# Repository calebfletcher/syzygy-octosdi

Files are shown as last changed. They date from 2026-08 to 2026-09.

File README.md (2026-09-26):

# syzygy-octosdi

SYZYGY™ TXR4 Compatible 3G-SDI Pod, with quad inputs and quad outputs.

Compatible with the SYZYGY Specification Version 1.1.1. The "SYZYGY™" mark is owned by Opal Kelly.

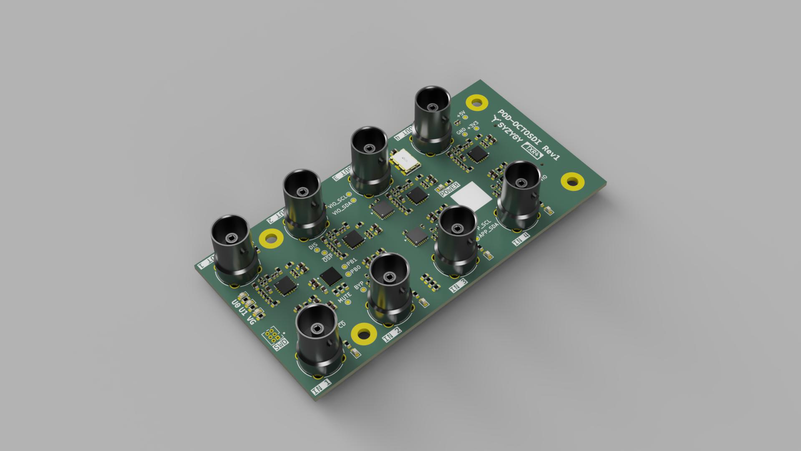
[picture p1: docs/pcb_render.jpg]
PCB Render


## Features
- SYZYGY TXR4 Pod
- 4x 3D-SDI inputs and 4x 3G-SDI outputs, all independent
- Full-size BNC connectors
- TI LMH0344 Cable Equalizers
- Semtech GS2988 Cable Drivers
- Lock/Signal Present LEDs at each BNC
- 148.5MHz oscillator on REFCLK
- I2C I/O expanders for all driver/equalizer control and status signals
- SmartVIO STM32G031 microcontroller with ability to measure VIO voltage

## Limitations
- Only 3G-SDI is supported
- There is no 148.5/1.001 MHz oscillator support
  - The board has only been designed for fractional framerates to keep the design a bit simpler. Depending on your FPGA, there may be enough tolerance on the MGT PLL to allow fractional rate inputs to be received despite it not being the correct frequency. This is the case at least for Xilinx Ultrascale+ GTYs with a +/-1250 ppm tolerance. However, this will not work for the transmitters which require the exact frequency.
- No reclockers on the board. It is designed to be plugged directly into an FPGA so this likely has no impact on its use.

## BOM Substitutions
While this board has been designed to use LMH0344 for the cable EQs and GS2988 for the cable drivers, there is broad compatibility across Semtech and TIs SDI portfolio. As such, some unpopulated footprints are available for passives needed for one chip or another, in particular for replacing the GS2988 with a LMH0302. See TI's SNLA280 for a full list of available substitutes for cable drivers, and SNLA283 for cable equalizers.

## [Interactive BOM](https://html-preview.github.io/?url=https://github.com/calebfletcher/syzygy-octosdi/blob/main/docs/ibom.html)

## Ordering Details
Designed to meet JLCPCBs standard capabilities.

Four layers, 1.6 mm, 1 oz outer/0.5 oz inner, JLC04161H-7628 stackup, controlled impedance.

## SYZYGY Compatibility Table

Following the pod compatibility table in [Appendix A of the SYZYGY Specification Version 1.1.1](https://syzygyfpga.io/wp-content/uploads/2023/09/Syzygy-Specification-V1p1p1.pdf):

| Parameter | syzygy-octosdi |
|---|---|
| Type | SYZYGY Transceiver (TXR-4) |
| Maximum 5V supply current | 0 mA |
| Maximum 3.3V supply current | 1.2 A (provisional design budget) |
| VIO supply voltage(s) | 1.8 V, 2.5 V, or 3.3 V |
| Maximum VIO supply current | 10 mA (provisional design budget) |
| Total number of I/O | 4 single-ended (S0–S3) |
| Number of differential I/O pairs (Standard pod only) | N/A (TXR-4 pod) |
| Transceiver lanes | 4 RX and 4 TX, plus REFCLK input |
| Width | Single |

The current budgets are conservative estimates from the schematic and component specifications; they have not been verified by measurement. The 5V pin is routed only to a test point. VIO powers the I/O side of the two expanders and the control-signal pull-ups.

## SYZYGY Pinout
Pinout for CN1 (QTH-020-01-F-D-DP-A):

| Pin number | Pin name | Pin net |
|---|---|---|
| 01 | SCL\_01 | VIO\_I2C.SCL |
| 02 | +5V\_02 | +5V |
| 03 | SDA\_03 | VIO\_I2C.SDA |
| 04 | R\_GA\_04 | R\_GA |
| 05 | RX0P\_05 | RX0.P |
| 06 | TX0P\_06 | TX0.P |
| 07 | RX0N\_07 | RX0.N |
| 08 | TX0N\_08 | TX0.N |
| 09 | RX1P\_09 | RX1.P |
| 10 | TX1P\_10 | TX1.P |
| 11 | RX1N\_11 | RX1.N |
| 12 | TX1N\_12 | TX1.N |
| 13 | REFCLKP\_13 | REFCLK.P |
| 14 | S0\_14 | I2C.SCL |
| 15 | REFCLKN\_15 | REFCLK.N |
| 16 | S1\_16 | I2C.SDA |
| 17 | S2\_17 | ~{RESET} |
| 18 | S3\_18 | ~{INT} |
| 19 | S4\_19 | NC |
| 20 | S5\_20 | NC |
| 21 | S6\_21 | NC |
| 22 | S7\_22 | NC |
| 23 | S8\_23 | NC |
| 24 | S9\_24 | NC |
| 25 | RX3P\_25 | RX3.P |
| 26 | TX3P\_26 | TX3.P |
| 27 | RX3N\_27 | RX3.N |
| 28 | TX3N\_28 | TX3.N |
| 29 | RX2P\_29 | RX2.P |
| 30 | TX2P\_30 | TX2.P |
| 31 | RX2N\_31 | RX2.N |
| 32 | TX2N\_32 | TX2.N |
| 33 | P2C\_CLKP\_33 | NC |
| 34 | C2P\_CLKP\_34 | NC |
| 35 | P2C\_CLKN\_35 | NC |
| 36 | C2P\_CLKN\_36 | NC |
| 37 | RSVD\_37 | NC |
| 38 | RSVD\_38 | NC |
| 39 | VIO1\_39 | VIO |
| 40 | +3.3V\_40 | +3V3 |
| G1 | GND\_G1 | GND |
| G2 | GND\_G2 | GND |
| G3 | GND\_G3 | GND |
| G4 | GND\_G4 | GND |

## SmartVIO STM32 Pinout
Pinout for U11 (STM32G031G8Ux):

| Pin number | Pin name | Pin net |
|---|---|---|
| 1 | PC14\_1 | NC |
| 2 | PC15\_2 | NC |
| 3 | VDD\_3 | +3V3 |
| 4 | VSS\_4 | GND |
| 5 | PF2\_5 | SmartVIO/NRST |
| 6 | ADC1\_IN0\_6 | R\_GA |
| 7 | ADC1\_IN1\_7 | VIO |
| 8 | PA2\_8 | VIO\_GOOD |
| 9 | PA3\_9 | ~{VIO\_GOOD} |
| 10 | PA4\_10 | NC |
| 11 | PA5\_11 | NC |
| 12 | PA6\_12 | NC |
| 13 | PA7\_13 | NC |
| 14 | PB0\_14 | Net-(U11-PB0) |
| 15 | PB1\_15 | Net-(U11-PB1) |
| 16 | PA8\_16 | NC |
| 17 | PC6\_17 | NC |
| 18 | PA9/PA11\_18 | NC |
| 19 | PA10/PA12\_19  | NC |
| 20 | SYS\_SWDIO\_20 | SmartVIO/SWDIO |
| 21 | SYS\_SWCLK\_21 | SmartVIO/SWCLK |
| 22 | PA15\_22 | NC |
| 23 | PB3\_23 | NC |
| 24 | PB4\_24 | SmartVIO/USER\_LED\_0 |
| 25 | PB5\_25 | SmartVIO/USER\_LED\_1 |
| 26 | I2C1\_SCL\_26  | VIO\_I2C.SCL |
| 27 | I2C1\_SDA\_27  | VIO\_I2C.SDA |
| 28 | PB8\_28 | NC |

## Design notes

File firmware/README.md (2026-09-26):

# SmartVIO LED and VIO ADC firmware

RTIC 2 keeps VIO_GOOD asserted, samples USER_LED_0's source at 10 Hz, and blinks USER_LED_1. Embassy STM32 owns the GPIO, ADC, and clock setup; TIM2 provides RTIC's monotonic clock. defmt logs are sent over RTT through the ST-Link.

| Signal or indicator | STM32 pin | Behaviour |
| --- | --- | --- |
| VIO_GOOD and its LED (D12) | PA2 | High continuously |
| VIO_GOOD_N | PA3 | Low continuously |
| USER_LED_0 (D11) | PB4 | Mirrors U6 P0.0 (SDI Out 1 SD_HD_N), sampled at 10 Hz |
| USER_LED_1 (D10) | PB5 | Blinks on for 1 s, off for 1 s |

VIO_GOOD and VIO_GOOD_N are asserted regardless of the measured voltage. VIO_GOOD also enables other board circuitry. Other board LEDs are driven by power or signal circuits, not directly by the STM32.

VIO is wired directly to PA1 / ADC1_IN1. The firmware samples VIO and the internal voltage reference every 100 ms and logs VIO in millivolts. It uses the factory VREF calibration to account for the actual ADC supply voltage.

At startup, I2C1 on PB6/PB7 accesses the two PCAL6416A expanders through the external VIO_I2C-to-APP_I2C bridge. U5 is at 7-bit address 0x20 and carries SDI input BYPASS, MUTE, and CD_N signals; U6 is at 0x21 and carries SDI output SD_HD_N, DISABLE_N, EQ_EN_N, and OSP_N signals. The firmware writes both configuration registers to 0xFF (all pins input), verifies them, and logs both raw port bytes and each named signal's electrical level once at startup (true = high, false = low; _N names remain active-low). Unconnected pins are omitted from the named logs. I2C errors are logged per device. After startup, U6 P0.0 is read every 100 ms to update USER_LED_0 (high = on); an I2C read error turns that LED off. The ADC is sampled on the same cycle.

From this directory:

    cargo build --release
    cargo run --release

cargo run flashes the STM32G031G8Ux using probe-rs and displays RTT logs. The target is thumbv6m-none-eabi and the probe uses SWD.

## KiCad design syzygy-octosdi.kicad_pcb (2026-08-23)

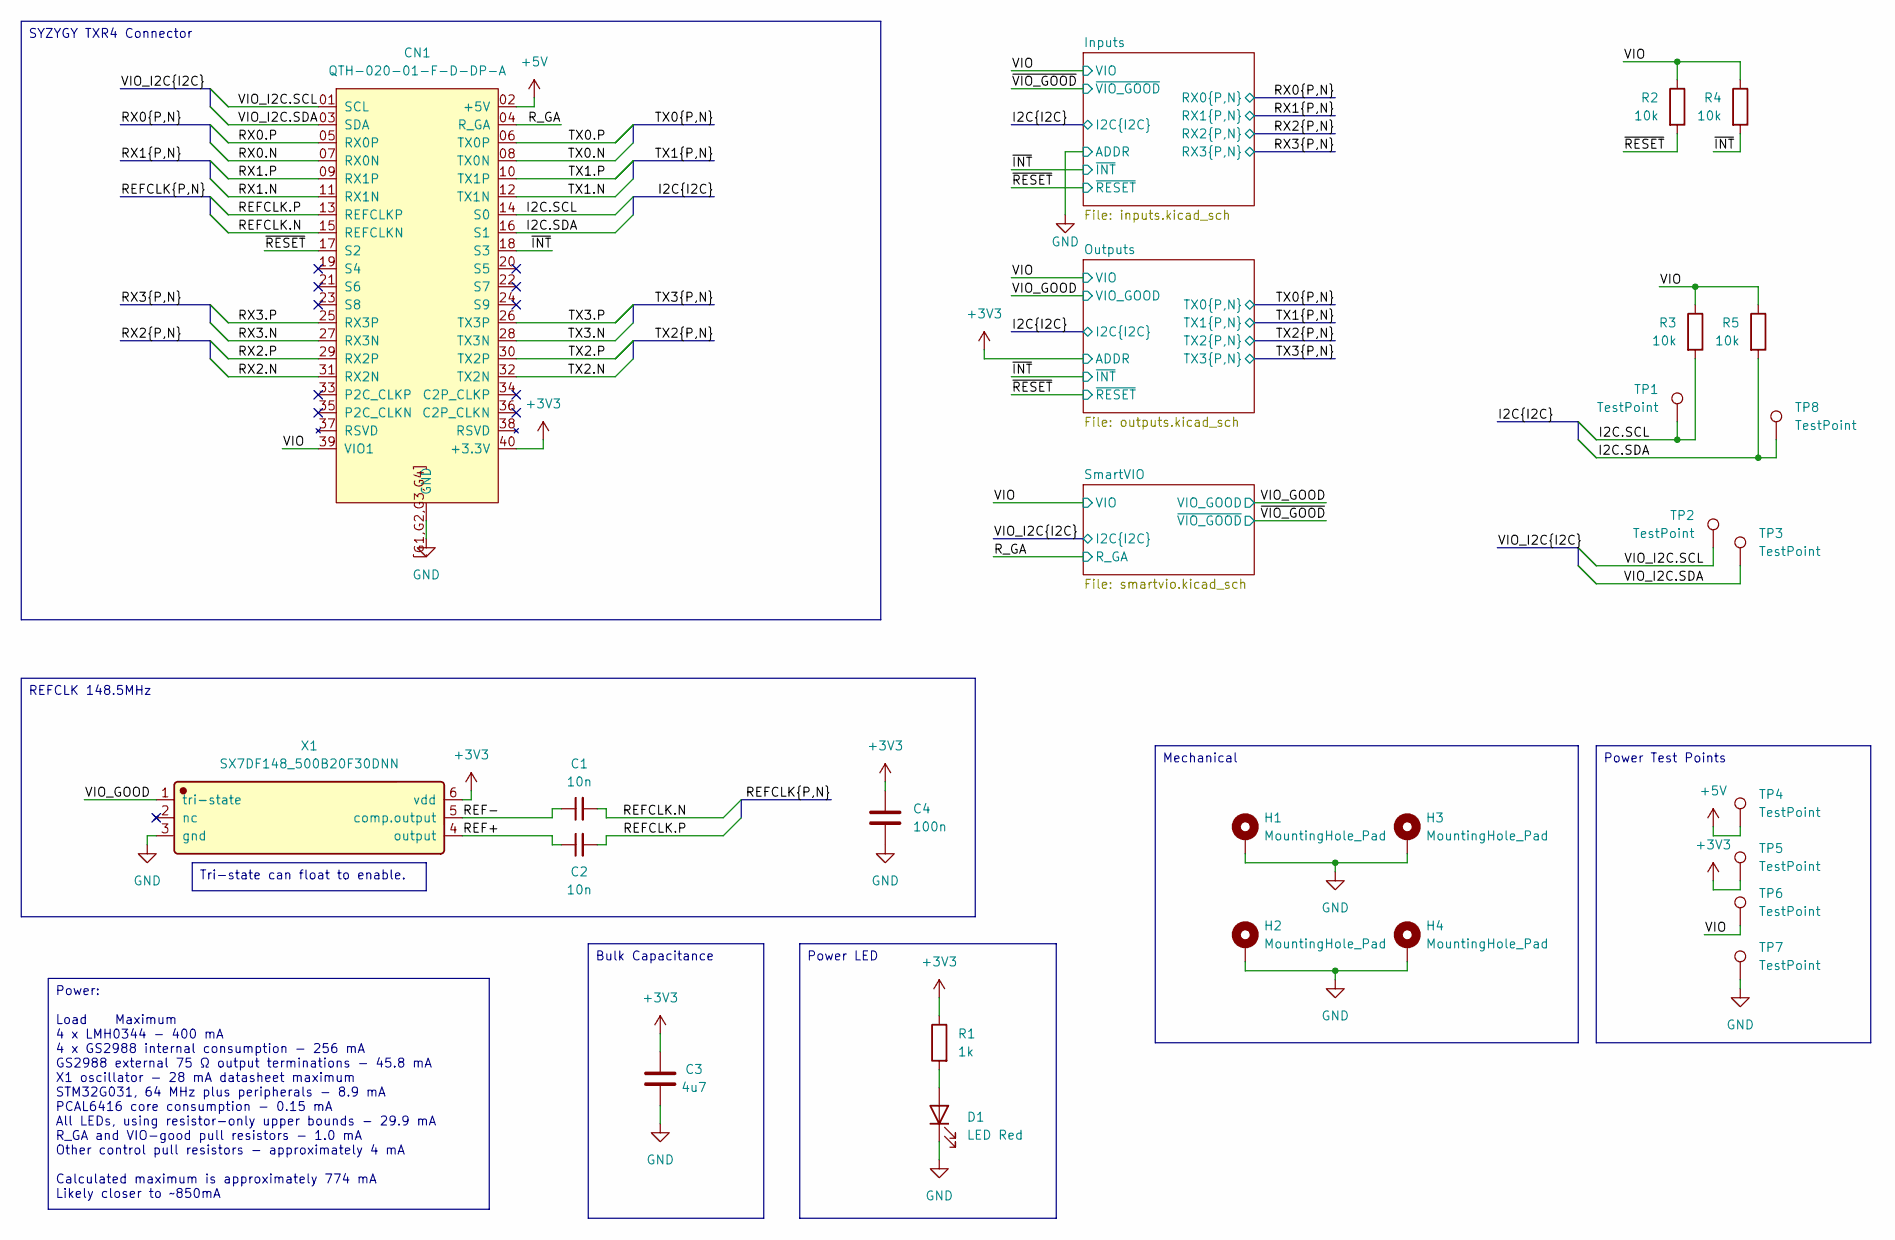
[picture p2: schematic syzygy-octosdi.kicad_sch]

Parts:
C1, C2: 10n; C_0402_1005Metric; LCSC C15195
C3: 4u7; C_0603_1608Metric; LCSC C69335
C4: 100n; C_0603_1608Metric; LCSC C282519
CN1: QTH-020-01-F-D-DP-A; Manufacturer Part QTH-020-01-F-D-DP-A; LCSC C5852101
D1: LED Red; LED_0603_1608Metric; LCSC C965799
H1, H2, H3, H4: MountingHole_Pad; MountingHole_3.2mm_M3_Pad
R1: 1k; R_0603_1608Metric; LCSC C21190
R2, R3, R4, R5: 10k; R_0603_1608Metric; LCSC C25804
TP1, TP2, TP3, TP4, TP5, TP6, TP7, TP8: TestPoint; TestPoint_Pad_D1.0mm
X1: SX7DF148_500B20F30DNN; Manufacturer Part SX7DF148.500B20F30DNN; LCSC C5179986

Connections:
+3V3: C3.1, C4.1, CN1.40 (+3.3V), R1.1, TP5.1 (1_1), X1.6 (vdd); also elsewhere on the board
+5V: CN1.02 (+5V), TP4.1 (1_1)
/I2C.SCL: CN1.14 (S0), R3.2, TP1.1 (1_1); also elsewhere on the board
/I2C.SDA: CN1.16 (S1), R5.2, TP8.1 (1_1); also elsewhere on the board
/REF+: C2.1, X1.4 (output)
/REF-: C1.1, X1.5 (comp.output)
/REFCLK.N: C1.2, CN1.15 (REFCLKN)
/REFCLK.P: C2.2, CN1.13 (REFCLKP)
/RX0.N: CN1.07 (RX0N); also elsewhere on the board
/RX0.P: CN1.05 (RX0P); also elsewhere on the board
/RX1.N: CN1.11 (RX1N); also elsewhere on the board
/RX1.P: CN1.09 (RX1P); also elsewhere on the board
/RX2.N: CN1.31 (RX2N); also elsewhere on the board
/RX2.P: CN1.29 (RX2P); also elsewhere on the board
/RX3.N: CN1.27 (RX3N); also elsewhere on the board
/RX3.P: CN1.25 (RX3P); also elsewhere on the board
/R_GA: CN1.04 (R_GA); also elsewhere on the board
/TX0.N: CN1.08 (TX0N); also elsewhere on the board
/TX0.P: CN1.06 (TX0P); also elsewhere on the board
/TX1.N: CN1.12 (TX1N); also elsewhere on the board
/TX1.P: CN1.10 (TX1P); also elsewhere on the board
/TX2.N: CN1.32 (TX2N); also elsewhere on the board
/TX2.P: CN1.30 (TX2P); also elsewhere on the board
/TX3.N: CN1.28 (TX3N); also elsewhere on the board
/TX3.P: CN1.26 (TX3P); also elsewhere on the board
/VIO: CN1.39 (VIO1), R2.1, R3.1, R4.1, R5.1, TP6.1 (1_1); also elsewhere on the board
/VIO_GOOD: X1.1 (tri-state); also elsewhere on the board
/VIO_I2C.SCL: CN1.01 (SCL), TP2.1 (1_1); also elsewhere on the board
/VIO_I2C.SDA: CN1.03 (SDA), TP3.1 (1_1); also elsewhere on the board
/~INT: CN1.18 (S3), R4.2; also elsewhere on the board
/~RESET: CN1.17 (S2), R2.2; also elsewhere on the board
GND: C3.2, C4.2, CN1.G1 (GND), CN1.G2 (GND), CN1.G3 (GND), CN1.G4 (GND), CN1.[G1,G2,G3,G4] (GND), D1.1 (K), H1.1 (1_1), H2.1 (1_1), H3.1 (1_1), H4.1 (1_1), TP7.1 (1_1), X1.3 (gnd); also elsewhere on the board
unnamed: D1.2 (A), R1.2

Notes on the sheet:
Power: Load Maximum 4 x LMH0344 - 400 mA 4 x GS2988 internal consumption - 256 mA GS2988 external 75 Ω output terminations - 45.8 mA X1 oscillator - 28 mA datasheet maximum STM32G031, 64 MHz plus peripherals - 8.9 mA PCAL6416 core consumption - 0.15 mA All LEDs, using resistor-only upper bounds - 2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
Mechanical
SYZYGY TXR4 Connector
Power Test Points
REFCLK 148.5MHz
Bulk Capacitance
Tri-state can float to enable.
Power LED

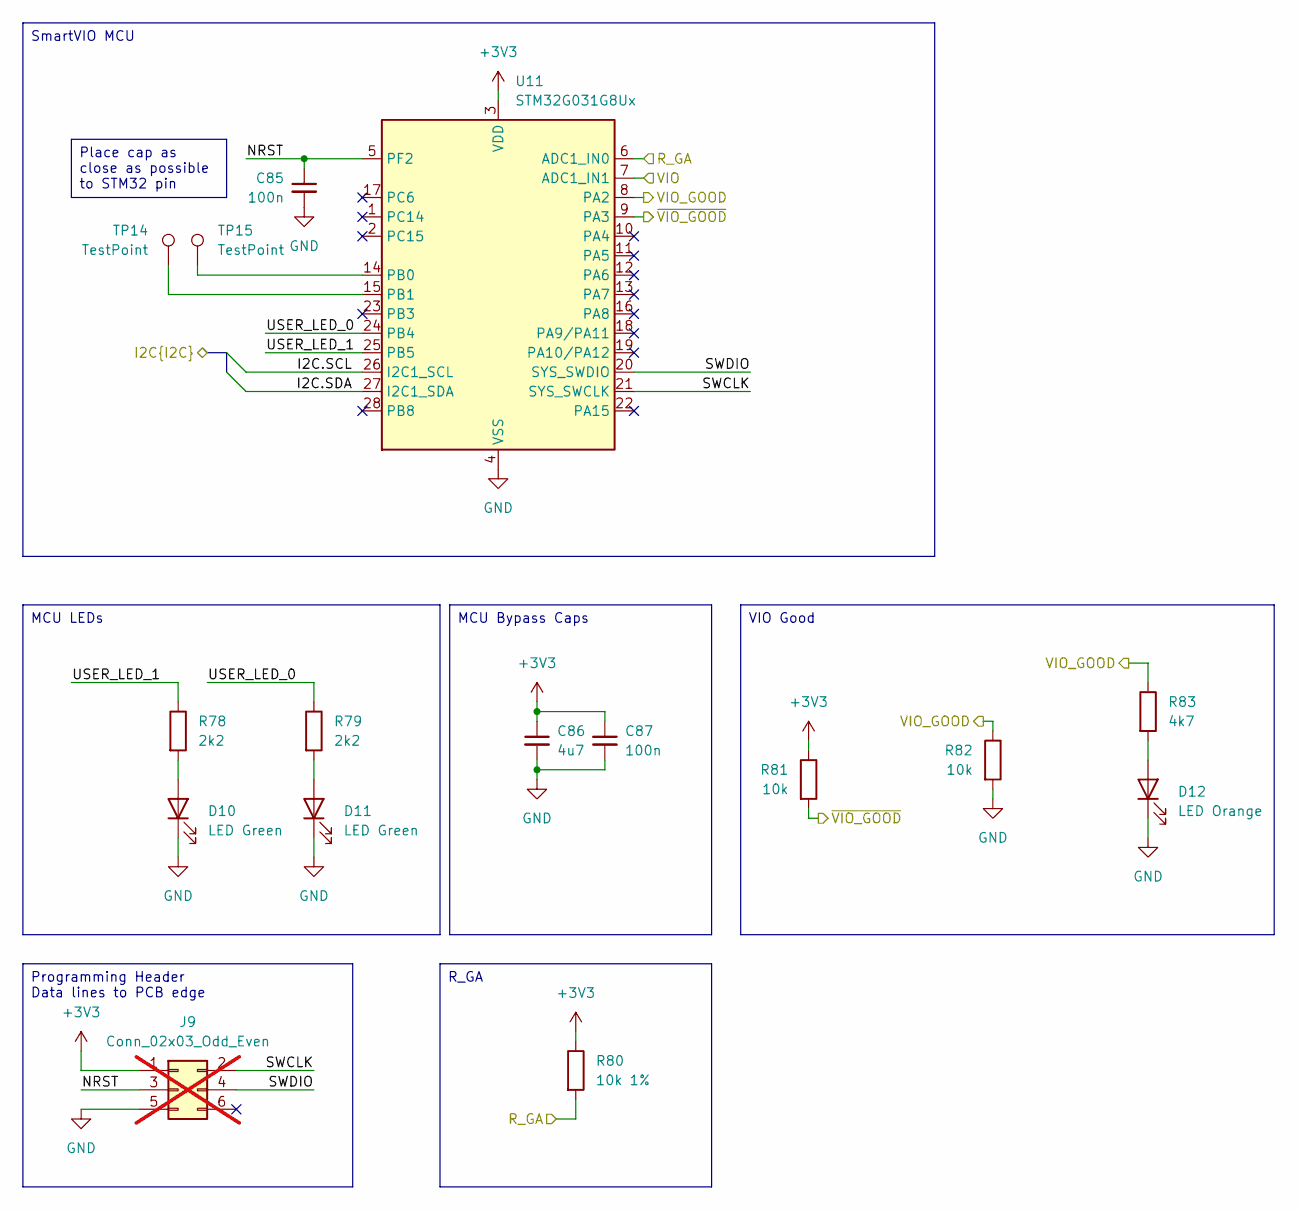
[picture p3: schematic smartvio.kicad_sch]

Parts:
C85, C87: 100n; C_0603_1608Metric; LCSC C282519
C86: 4u7; C_0603_1608Metric; LCSC C69335
D10, D11: LED Green; LED_0603_1608Metric; LCSC C965804
D12: LED Orange; LED_0603_1608Metric; LCSC C965800
J9: Conn_02x03_Odd_Even; PinHeader_2x03_P1.27mm_Vertical; not fitted
R78, R79: 2k2; R_0603_1608Metric; LCSC C2907005
R80: 10k 1%; R_0603_1608Metric; LCSC C25804
R81, R82: 10k; R_0603_1608Metric; LCSC C25804
R83: 4k7; R_0603_1608Metric; LCSC C2907034
TP14, TP15: TestPoint; TestPoint_Pad_D1.0mm
U11: STM32G031G8Ux; UFQFPN-28_STM; LCSC C432211

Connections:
+3V3: C86.1, C87.1, J9.1, R80.1, R81.1, U11.3 (VDD); also elsewhere on the board
/R_GA: R80.2, U11.6 (ADC1_IN0); also elsewhere on the board
/SmartVIO/NRST: C85.1, J9.3, U11.5 (PF2)
/SmartVIO/SWCLK: J9.2, U11.21 (SYS_SWCLK)
/SmartVIO/SWDIO: J9.4, U11.20 (SYS_SWDIO)
/SmartVIO/USER_LED_0: R79.1, U11.24 (PB4)
/SmartVIO/USER_LED_1: R78.1, U11.25 (PB5)
/VIO: U11.7 (ADC1_IN1); also elsewhere on the board
/VIO_GOOD: R82.1, R83.1, U11.8 (PA2); also elsewhere on the board
/VIO_I2C.SCL: U11.26 (I2C1_SCL); also elsewhere on the board
/VIO_I2C.SDA: U11.27 (I2C1_SDA); also elsewhere on the board
/~VIO_GOOD: R81.2, U11.9 (PA3); also elsewhere on the board
GND: C85.2, C86.2, C87.2, D10.1 (K), D11.1 (K), D12.1 (K), J9.5, R82.2, U11.4 (VSS); also elsewhere on the board
unnamed: D10.2 (A), R78.2
unnamed: D11.2 (A), R79.2
unnamed: D12.2 (A), R83.2
unnamed: TP15.1 (1_1), U11.14 (PB0)
unnamed: TP14.1 (1_1), U11.15 (PB1)

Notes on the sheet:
MCU Bypass Caps
VIO Good
MCU LEDs
Programming Header Data lines to PCB edge
Place cap as close as possible to STM32 pin
SmartVIO MCU
R_GA

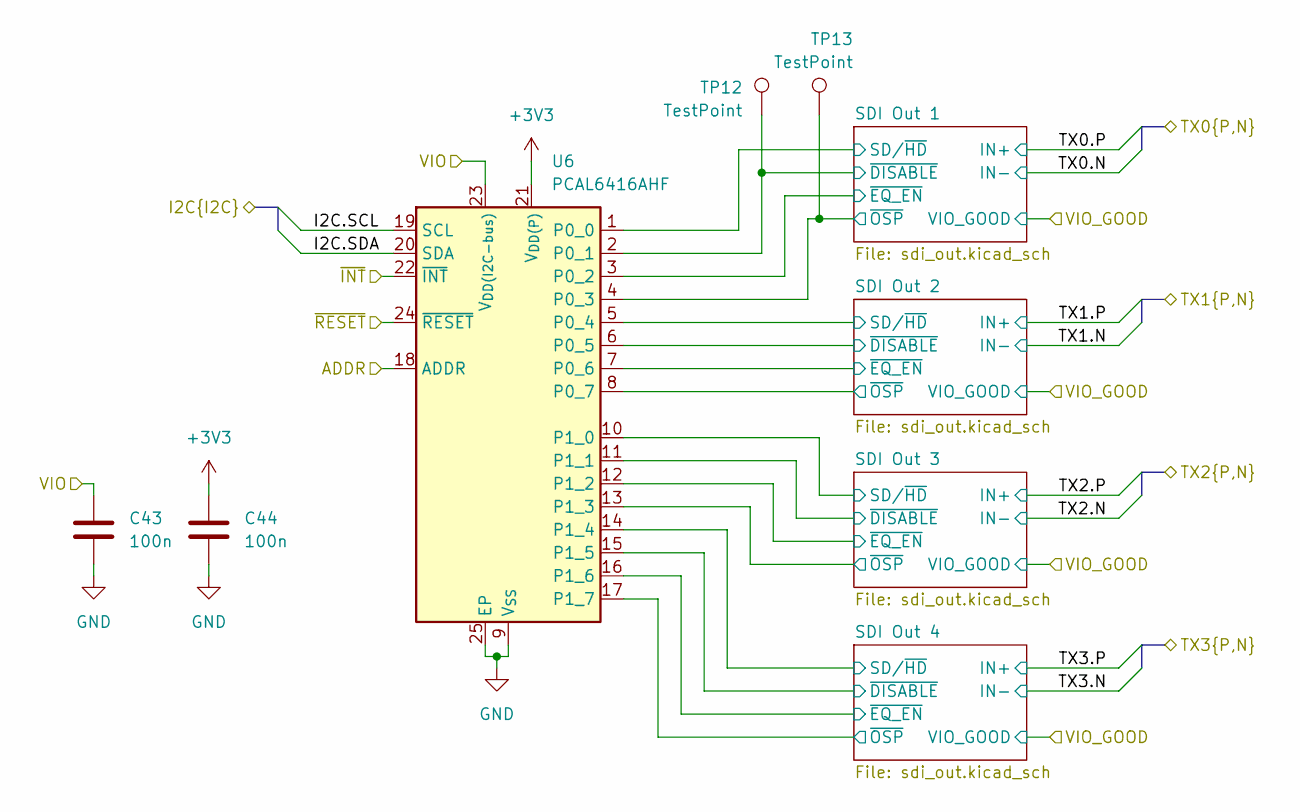
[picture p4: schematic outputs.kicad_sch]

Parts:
C43, C44: 100n; C_0402_1005Metric; LCSC C1525
TP12, TP13: TestPoint; TestPoint_Pad_D1.0mm
U6: PCAL6416AHF; HVQFN-24-1EP_4x4mm_P0.5mm_EP2.1x2.1mm; LCSC C2652287

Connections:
+3V3: C44.1, U6.18 (ADDR), U6.21 (V_{DD(P)}); also elsewhere on the board
/I2C.SCL: U6.19 (SCL); also elsewhere on the board
/I2C.SDA: U6.20 (SDA); also elsewhere on the board
/Outputs/SDI Out 1/SD/~HD: U6.1 (P0_0); also elsewhere on the board
/Outputs/SDI Out 1/~DISABLE: TP12.1 (1_1), U6.2 (P0_1); also elsewhere on the board
/Outputs/SDI Out 1/~EQ_EN: U6.3 (P0_2); also elsewhere on the board
/Outputs/SDI Out 1/~OSP: TP13.1 (1_1), U6.4 (P0_3); also elsewhere on the board
/Outputs/SDI Out 2/SD/~HD: U6.5 (P0_4); also elsewhere on the board
/Outputs/SDI Out 2/~DISABLE: U6.6 (P0_5); also elsewhere on the board
/Outputs/SDI Out 2/~EQ_EN: U6.7 (P0_6); also elsewhere on the board
/Outputs/SDI Out 2/~OSP: U6.8 (P0_7); also elsewhere on the board
/Outputs/SDI Out 3/SD/~HD: U6.10 (P1_0); also elsewhere on the board
/Outputs/SDI Out 3/~DISABLE: U6.11 (P1_1); also elsewhere on the board
/Outputs/SDI Out 3/~EQ_EN: U6.12 (P1_2); also elsewhere on the board
/Outputs/SDI Out 3/~OSP: U6.13 (P1_3); also elsewhere on the board
/Outputs/SDI Out 4/SD/~HD: U6.14 (P1_4); also elsewhere on the board
/Outputs/SDI Out 4/~DISABLE: U6.15 (P1_5); also elsewhere on the board
/Outputs/SDI Out 4/~EQ_EN: U6.16 (P1_6); also elsewhere on the board
/Outputs/SDI Out 4/~OSP: U6.17 (P1_7); also elsewhere on the board
/VIO: C43.1, U6.23 (V_{DD(I2C-bus)}); also elsewhere on the board
/~INT: U6.22 (~INT); also elsewhere on the board
/~RESET: U6.24 (~RESET); also elsewhere on the board
GND: C43.2, C44.2, U6.9 (V_{SS}), U6.25 (EP); also elsewhere on the board

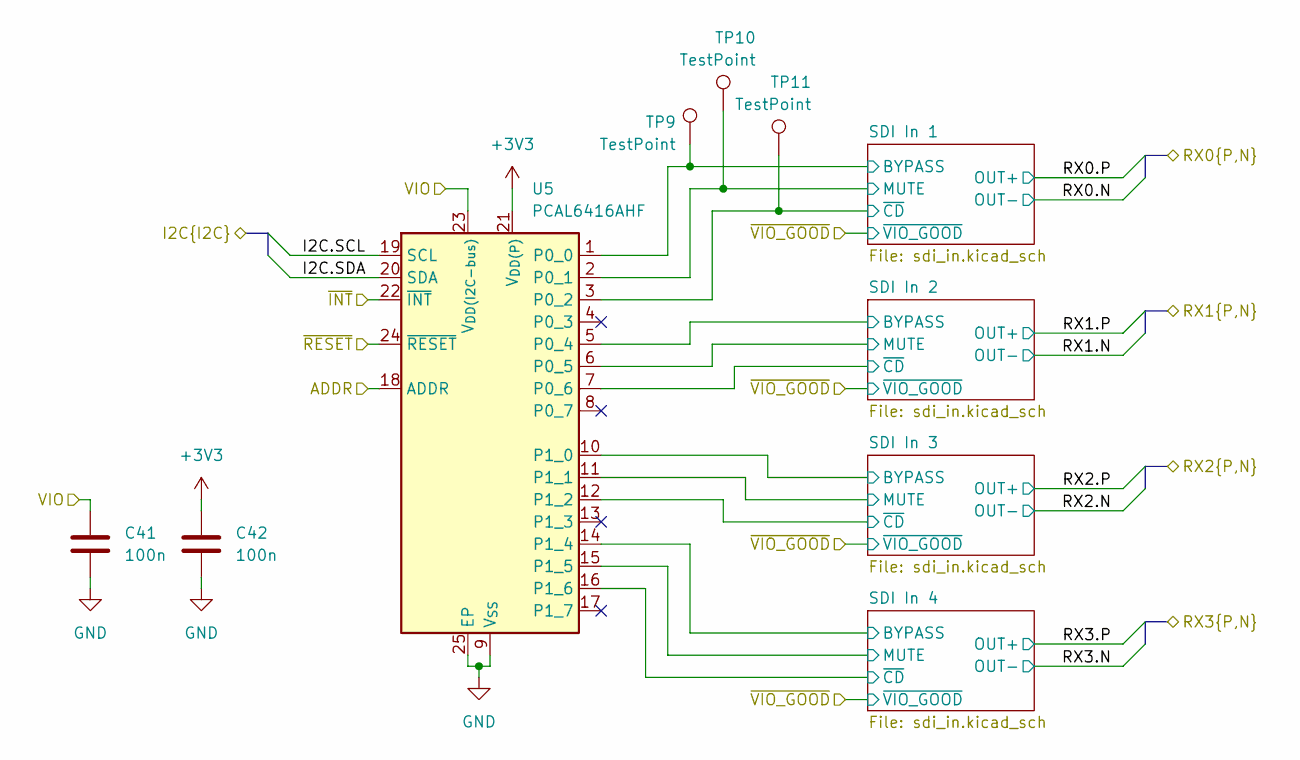
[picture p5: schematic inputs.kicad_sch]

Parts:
C41, C42: 100n; C_0402_1005Metric; LCSC C1525
TP9, TP10, TP11: TestPoint; TestPoint_Pad_D1.0mm
U5: PCAL6416AHF; HVQFN-24-1EP_4x4mm_P0.5mm_EP2.1x2.1mm; LCSC C2652287

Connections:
+3V3: C42.1, U5.21 (V_{DD(P)}); also elsewhere on the board
/I2C.SCL: U5.19 (SCL); also elsewhere on the board
/I2C.SDA: U5.20 (SDA); also elsewhere on the board
/Inputs/SDI In 1/BYPASS: TP9.1 (1_1), U5.1 (P0_0); also elsewhere on the board
/Inputs/SDI In 1/MUTE: TP10.1 (1_1), U5.2 (P0_1); also elsewhere on the board
/Inputs/SDI In 1/~CD: TP11.1 (1_1), U5.3 (P0_2); also elsewhere on the board
/Inputs/SDI In 2/BYPASS: U5.5 (P0_4); also elsewhere on the board
/Inputs/SDI In 2/MUTE: U5.6 (P0_5); also elsewhere on the board
/Inputs/SDI In 2/~CD: U5.7 (P0_6); also elsewhere on the board
/Inputs/SDI In 3/BYPASS: U5.10 (P1_0); also elsewhere on the board
/Inputs/SDI In 3/MUTE: U5.11 (P1_1); also elsewhere on the board
/Inputs/SDI In 3/~CD: U5.12 (P1_2); also elsewhere on the board
/Inputs/SDI In 4/BYPASS: U5.14 (P1_4); also elsewhere on the board
/Inputs/SDI In 4/MUTE: U5.15 (P1_5); also elsewhere on the board
/Inputs/SDI In 4/~CD: U5.16 (P1_6); also elsewhere on the board
/VIO: C41.1, U5.23 (V_{DD(I2C-bus)}); also elsewhere on the board
/~INT: U5.22 (~INT); also elsewhere on the board
/~RESET: U5.24 (~RESET); also elsewhere on the board
GND: C41.2, C42.2, U5.9 (V_{SS}), U5.18 (ADDR), U5.25 (EP); also elsewhere on the board

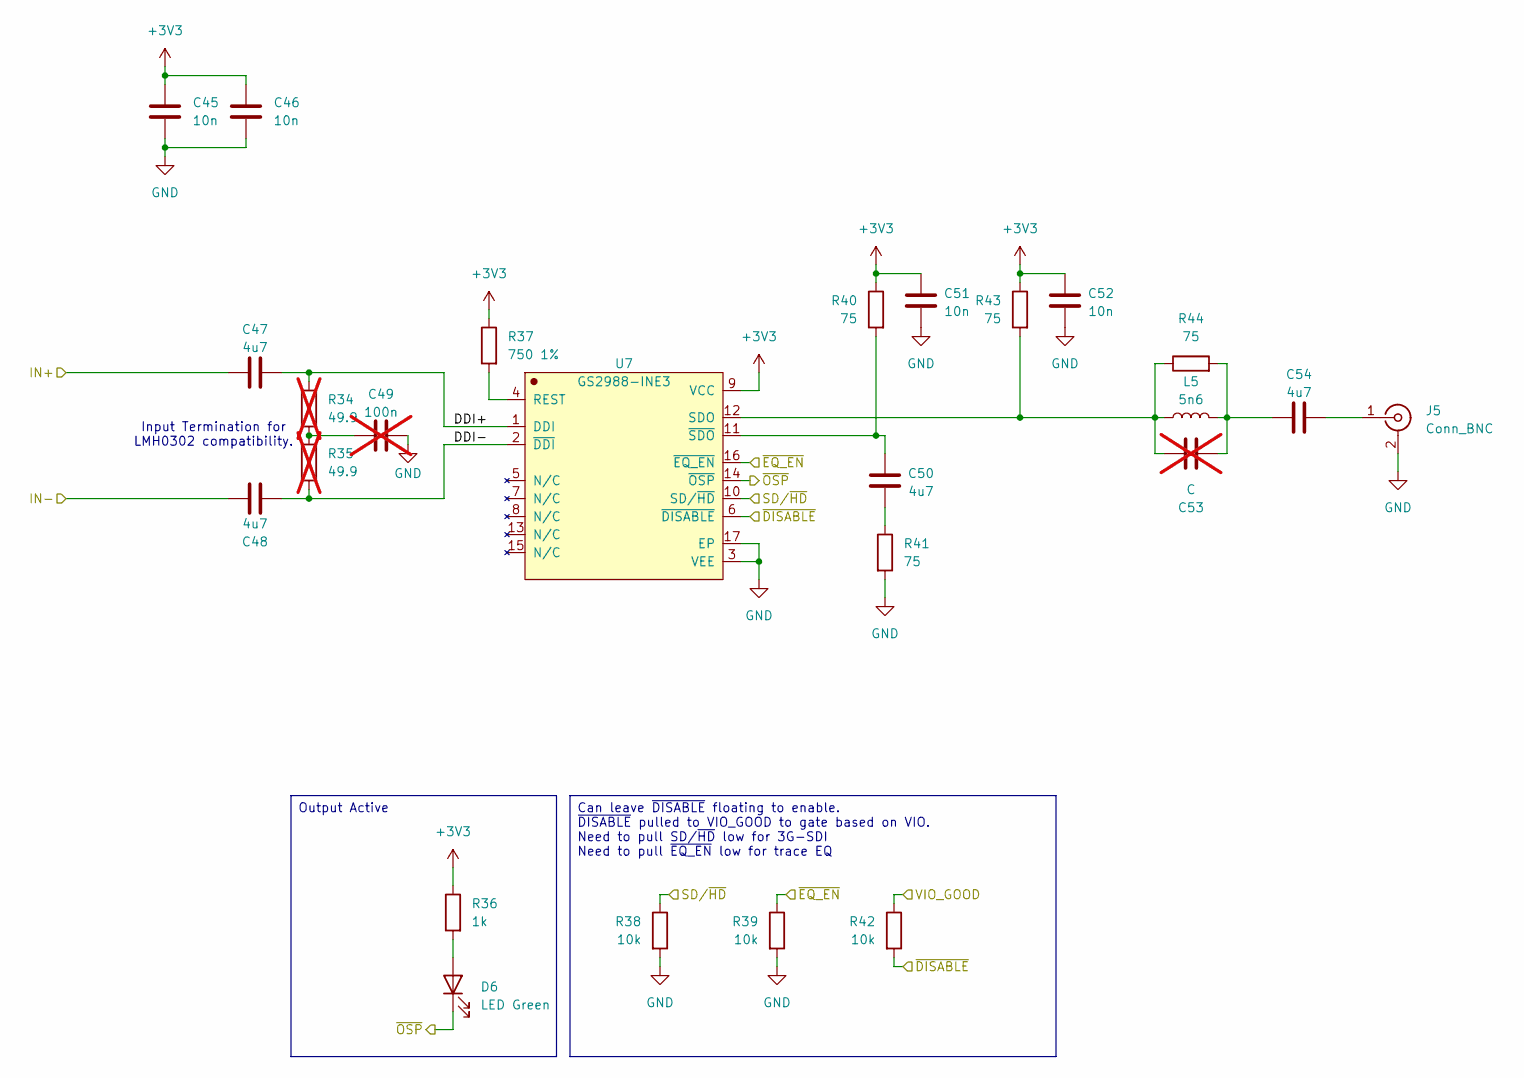
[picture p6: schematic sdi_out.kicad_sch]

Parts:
C45, C46, C51, C52: 10n; C_0402_1005Metric; LCSC C15195
C47, C48, C50, C54: 4u7; C_0603_1608Metric; LCSC C69335
C49: 100n; C_0402_1005Metric; LCSC C1525; not fitted
C53: C; C_0402_1005Metric; not fitted
D6: LED Green; LED_0603_1608Metric; LCSC C965804
J5: Conn_BNC; CONN_73171-1900_MOL; Manufacturer Part 731711900
L5: 5n6; L_0402_1005Metric; LCSC C3223990
R34, R35: 49.9; R_0402_1005Metric; not fitted
R36: 1k; R_0603_1608Metric; LCSC C21190
R37: 750 1%; R_0603_1608Metric; LCSC C118388
R38, R39, R42: 10k; R_0603_1608Metric; LCSC C25804
R40, R41, R43, R44: 75; R_0402_1005Metric; LCSC C324774
U7: GS2988-INE3; Manufacturer Part GS2988-INE3; LCSC C5367442

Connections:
+3V3: C45.1, C46.1, C51.1, C52.1, R36.1, R37.1, R40.1, R43.1, U7.9 (VCC); also elsewhere on the board
/Outputs/SDI Out 1/DDI+: C47.2, R34.1, U7.1 (DDI)
/Outputs/SDI Out 1/DDI-: C48.2, R35.2, U7.2 (~DDI)
/Outputs/SDI Out 1/SD/~HD: R38.1, U7.10 (SD/~HD); also elsewhere on the board
/Outputs/SDI Out 1/~DISABLE: R42.2, U7.6 (~DISABLE); also elsewhere on the board
/Outputs/SDI Out 1/~EQ_EN: R39.1, U7.16 (~EQ_EN); also elsewhere on the board
/Outputs/SDI Out 1/~OSP: D6.1 (K), U7.14 (~OSP); also elsewhere on the board
/TX0.N: C48.1; also elsewhere on the board
/TX0.P: C47.1; also elsewhere on the board
/VIO_GOOD: R42.1; also elsewhere on the board
GND: C45.2, C46.2, C49.2, C51.2, C52.2, J5.2 (Ext), R38.2, R39.2, R41.2, U7.3 (VEE), U7.17 (EP); also elsewhere on the board
unnamed: C49.1, R34.2, R35.1
unnamed: C50.2, R41.1
unnamed: C53.2, C54.1, L5.2, R44.2
unnamed: D6.2 (A), R36.2
unnamed: C54.2, J5.1 (In)
unnamed: R37.2, U7.4 (REST)
unnamed: C53.1, L5.1, R43.2, R44.1, U7.12 (SDO)
unnamed: C50.1, R40.2, U7.11 (~SDO)

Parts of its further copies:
C55, C56, C61, C62, C65, C66, C71, C72, C75, C76, C81, C82: 10n; C_0402_1005Metric; LCSC C15195
C57, C58, C60, C64, C67, C68, C70, C74, C77, C78, C80, C84: 4u7; C_0603_1608Metric; LCSC C69335
C59, C69, C79: 100n; C_0402_1005Metric; LCSC C1525; not fitted
C63, C73, C83: C; C_0402_1005Metric; not fitted
D7, D8, D9: LED Green; LED_0603_1608Metric; LCSC C965804
J6, J7, J8: Conn_BNC; CONN_73171-1900_MOL; Manufacturer Part 731711900
L6, L7, L8: 5n6; L_0402_1005Metric; LCSC C3223990
R45, R46, R56, R57, R67, R68: 49.9; R_0402_1005Metric; not fitted
R47, R58, R69: 1k; R_0603_1608Metric; LCSC C21190
R48, R59, R70: 750 1%; R_0603_1608Metric; LCSC C118388
R49, R50, R53, R60, R61, R64, R71, R72, R75: 10k; R_0603_1608Metric; LCSC C25804
R51, R52, R54, R55, R62, R63, R65, R66, R73, R74, R76, R77: 75; R_0402_1005Metric; LCSC C324774
U8, U9, U10: GS2988-INE3; Manufacturer Part GS2988-INE3; LCSC C5367442

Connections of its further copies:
+3V3: C55.1, C56.1, C61.1, C62.1, C65.1, C66.1, C71.1, C72.1, C75.1, C76.1, C81.1, C82.1, R47.1, R48.1, R51.1, R54.1, R58.1, R59.1, R62.1, R65.1, R69.1, R70.1, R73.1, R76.1, U8.9 (VCC), U9.9 (VCC), U10.9 (VCC); also elsewhere on the board
/Outputs/SDI Out 2/DDI+: C57.2, R45.1, U8.1 (DDI)
/Outputs/SDI Out 2/DDI-: C58.2, R46.2, U8.2 (~DDI)
/Outputs/SDI Out 2/SD/~HD: R49.1, U8.10 (SD/~HD); also elsewhere on the board
/Outputs/SDI Out 2/~DISABLE: R53.2, U8.6 (~DISABLE); also elsewhere on the board
/Outputs/SDI Out 2/~EQ_EN: R50.1, U8.16 (~EQ_EN); also elsewhere on the board
/Outputs/SDI Out 2/~OSP: D7.1 (K), U8.14 (~OSP); also elsewhere on the board
/Outputs/SDI Out 3/DDI+: C67.2, R56.1, U9.1 (DDI)
/Outputs/SDI Out 3/DDI-: C68.2, R57.2, U9.2 (~DDI)
/Outputs/SDI Out 3/SD/~HD: R60.1, U9.10 (SD/~HD); also elsewhere on the board
/Outputs/SDI Out 3/~DISABLE: R64.2, U9.6 (~DISABLE); also elsewhere on the board
/Outputs/SDI Out 3/~EQ_EN: R61.1, U9.16 (~EQ_EN); also elsewhere on the board
/Outputs/SDI Out 3/~OSP: D8.1 (K), U9.14 (~OSP); also elsewhere on the board
/Outputs/SDI Out 4/DDI+: C77.2, R67.1, U10.1 (DDI)
/Outputs/SDI Out 4/DDI-: C78.2, R68.2, U10.2 (~DDI)
/Outputs/SDI Out 4/SD/~HD: R71.1, U10.10 (SD/~HD); also elsewhere on the board
/Outputs/SDI Out 4/~DISABLE: R75.2, U10.6 (~DISABLE); also elsewhere on the board
/Outputs/SDI Out 4/~EQ_EN: R72.1, U10.16 (~EQ_EN); also elsewhere on the board
/Outputs/SDI Out 4/~OSP: D9.1 (K), U10.14 (~OSP); also elsewhere on the board
/TX1.N: C58.1; also elsewhere on the board
/TX1.P: C57.1; also elsewhere on the board
/TX2.N: C68.1; also elsewhere on the board
/TX2.P: C67.1; also elsewhere on the board
/TX3.N: C78.1; also elsewhere on the board
/TX3.P: C77.1; also elsewhere on the board
/VIO_GOOD: R53.1, R64.1, R75.1; also elsewhere on the board
GND: C55.2, C56.2, C59.2, C61.2, C62.2, C65.2, C66.2, C69.2, C71.2, C72.2, C75.2, C76.2, C79.2, C81.2, C82.2, J6.2 (Ext), J7.2 (Ext), J8.2 (Ext), R49.2, R50.2, R52.2, R60.2, R61.2, R63.2, R71.2, R72.2, R74.2, U8.3 (VEE), U8.17 (EP), U9.3 (VEE), U9.17 (EP), U10.3 (VEE), U10.17 (EP); also elsewhere on the board
unnamed: C59.1, R45.2, R46.1
unnamed: C60.2, R52.1
unnamed: C63.2, C64.1, L6.2, R55.2
unnamed: C69.1, R56.2, R57.1
unnamed: C70.2, R63.1
unnamed: C73.2, C74.1, L7.2, R66.2
unnamed: C79.1, R67.2, R68.1
unnamed: C80.2, R74.1
unnamed: C83.2, C84.1, L8.2, R77.2
unnamed: D7.2 (A), R47.2
unnamed: D8.2 (A), R58.2
unnamed: D9.2 (A), R69.2
unnamed: C64.2, J6.1 (In)
unnamed: C74.2, J7.1 (In)
unnamed: C84.2, J8.1 (In)
unnamed: R48.2, U8.4 (REST)
unnamed: C63.1, L6.1, R54.2, R55.1, U8.12 (SDO)
unnamed: C60.1, R51.2, U8.11 (~SDO)
unnamed: R59.2, U9.4 (REST)
unnamed: C73.1, L7.1, R65.2, R66.1, U9.12 (SDO)
unnamed: C70.1, R62.2, U9.11 (~SDO)
unnamed: R70.2, U10.4 (REST)
unnamed: C83.1, L8.1, R76.2, R77.1, U10.12 (SDO)
unnamed: C80.1, R73.2, U10.11 (~SDO)

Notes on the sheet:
Input Termination for LMH0302 compatibility.
Output Active
Can leave ~{DISABLE} floating to enable. ~{DISABLE} pulled to VIO_GOOD to gate based on VIO. Need to pull SD/~{HD} low for 3G-SDI Need to pull ~{EQ_EN} low for trace EQ

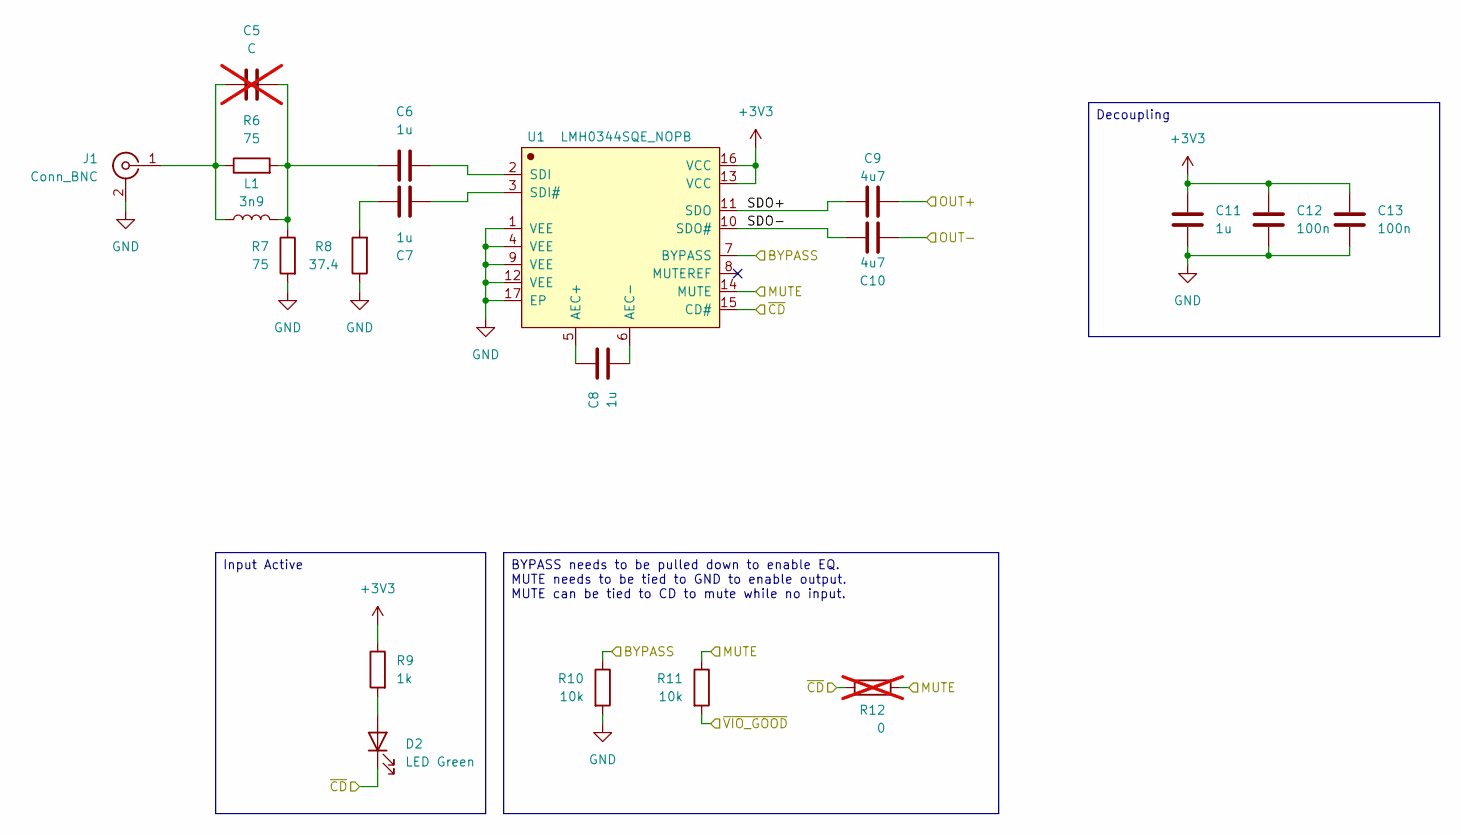
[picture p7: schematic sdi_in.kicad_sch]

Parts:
C5: C; C_0402_1005Metric; not fitted
C6, C7: 1u; C_0402_1005Metric; LCSC C49210445
C8, C11: 1u; C_0603_1608Metric; LCSC C6119818
C9, C10: 4u7; C_0603_1608Metric; LCSC C69335
C12, C13: 100n; C_0603_1608Metric; LCSC C282519
D2: LED Green; LED_0603_1608Metric; LCSC C965804
J1: Conn_BNC; CONN_73171-1900_MOL; Manufacturer Part 731711900
L1: 3n9; L_0402_1005Metric; LCSC C412279
R6, R7: 75; R_0402_1005Metric; LCSC C324774
R8: 37.4; R_0402_1005Metric; LCSC C2091522
R9: 1k; R_0603_1608Metric; LCSC C21190
R10, R11: 10k; R_0603_1608Metric; LCSC C25804
R12: 0; R_0603_1608Metric; LCSC C15402; not fitted
U1: LMH0344SQE_NOPB; WQFN-16-1EP_4x4mm_P0.65mm_EP2.6x2.6mm_ThermalVias; Manufacturer Part LMH0344SQE/NOPB; LCSC C2652894

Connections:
+3V3: C11.1, C12.1, C13.1, R9.1, U1.13 (VCC), U1.16 (VCC); also elsewhere on the board
/Inputs/SDI In 1/BYPASS: R10.1, U1.7 (BYPASS); also elsewhere on the board
/Inputs/SDI In 1/MUTE: R11.1, R12.2, U1.14 (MUTE); also elsewhere on the board
/Inputs/SDI In 1/SDO+: C9.1, U1.11 (SDO)
/Inputs/SDI In 1/SDO-: C10.1, U1.10 (SDO#)
/Inputs/SDI In 1/~CD: D2.1 (K), R12.1, U1.15 (CD#); also elsewhere on the board
/RX0.N: C10.2; also elsewhere on the board
/RX0.P: C9.2; also elsewhere on the board
/~VIO_GOOD: R11.2; also elsewhere on the board
GND: C11.2, C12.2, C13.2, J1.2 (Ext), R7.2, R8.1, R10.2, U1.1 (VEE), U1.4 (VEE), U1.9 (VEE), U1.12 (VEE), U1.17 (EP); also elsewhere on the board
unnamed: C5.2, C6.1, L1.2, R6.2, R7.1
unnamed: C7.1, R8.2
unnamed: D2.2 (A), R9.2
unnamed: C5.1, J1.1 (In), L1.1, R6.1
unnamed: C8.1, U1.5 (AEC+)
unnamed: C8.2, U1.6 (AEC-)
unnamed: C7.2, U1.3 (SDI#)
unnamed: C6.2, U1.2 (SDI)

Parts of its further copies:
C14, C23, C32: C; C_0402_1005Metric; not fitted
C15, C16, C24, C25, C33, C34: 1u; C_0402_1005Metric; LCSC C49210445
C17, C20, C26, C29, C35, C38: 1u; C_0603_1608Metric; LCSC C6119818
C18, C19, C27, C28, C36, C37: 4u7; C_0603_1608Metric; LCSC C69335
C21, C22, C30, C31, C39, C40: 100n; C_0603_1608Metric; LCSC C282519
D3, D4, D5: LED Green; LED_0603_1608Metric; LCSC C965804
J2, J3, J4: Conn_BNC; CONN_73171-1900_MOL; Manufacturer Part 731711900
L2, L3, L4: 3n9; L_0402_1005Metric; LCSC C412279
R13, R14, R20, R21, R27, R28: 75; R_0402_1005Metric; LCSC C324774
R15, R22, R29: 37.4; R_0402_1005Metric; LCSC C2091522
R16, R23, R30: 1k; R_0603_1608Metric; LCSC C21190
R17, R18, R24, R25, R31, R32: 10k; R_0603_1608Metric; LCSC C25804
R19, R26, R33: 0; R_0603_1608Metric; LCSC C15402; not fitted
U2, U3, U4: LMH0344SQE_NOPB; WQFN-16-1EP_4x4mm_P0.65mm_EP2.6x2.6mm_ThermalVias; Manufacturer Part LMH0344SQE/NOPB; LCSC C2652894

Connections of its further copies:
+3V3: C20.1, C21.1, C22.1, C29.1, C30.1, C31.1, C38.1, C39.1, C40.1, R16.1, R23.1, R30.1, U2.13 (VCC), U2.16 (VCC), U3.13 (VCC), U3.16 (VCC), U4.13 (VCC), U4.16 (VCC); also elsewhere on the board
/Inputs/SDI In 2/BYPASS: R17.1, U2.7 (BYPASS); also elsewhere on the board
/Inputs/SDI In 2/MUTE: R18.1, R19.2, U2.14 (MUTE); also elsewhere on the board
/Inputs/SDI In 2/SDO+: C18.1, U2.11 (SDO)
/Inputs/SDI In 2/SDO-: C19.1, U2.10 (SDO#)
/Inputs/SDI In 2/~CD: D3.1 (K), R19.1, U2.15 (CD#); also elsewhere on the board
/Inputs/SDI In 3/BYPASS: R24.1, U3.7 (BYPASS); also elsewhere on the board
/Inputs/SDI In 3/MUTE: R25.1, R26.2, U3.14 (MUTE); also elsewhere on the board
/Inputs/SDI In 3/SDO+: C27.1, U3.11 (SDO)
/Inputs/SDI In 3/SDO-: C28.1, U3.10 (SDO#)
/Inputs/SDI In 3/~CD: D4.1 (K), R26.1, U3.15 (CD#); also elsewhere on the board
/Inputs/SDI In 4/BYPASS: R31.1, U4.7 (BYPASS); also elsewhere on the board
/Inputs/SDI In 4/MUTE: R32.1, R33.2, U4.14 (MUTE); also elsewhere on the board
/Inputs/SDI In 4/SDO+: C36.1, U4.11 (SDO)
/Inputs/SDI In 4/SDO-: C37.1, U4.10 (SDO#)
/Inputs/SDI In 4/~CD: D5.1 (K), R33.1, U4.15 (CD#); also elsewhere on the board
/RX1.N: C19.2; also elsewhere on the board
/RX1.P: C18.2; also elsewhere on the board
/RX2.N: C28.2; also elsewhere on the board
/RX2.P: C27.2; also elsewhere on the board
/RX3.N: C37.2; also elsewhere on the board
/RX3.P: C36.2; also elsewhere on the board
/~VIO_GOOD: R18.2, R25.2, R32.2; also elsewhere on the board
GND: C20.2, C21.2, C22.2, C29.2, C30.2, C31.2, C38.2, C39.2, C40.2, J2.2 (Ext), J3.2 (Ext), J4.2 (Ext), R14.2, R15.1, R17.2, R21.2, R22.1, R24.2, R28.2, R29.1, R31.2, U2.1 (VEE), U2.4 (VEE), U2.9 (VEE), U2.12 (VEE), U2.17 (EP), U3.1 (VEE), U3.4 (VEE), U3.9 (VEE), U3.12 (VEE), U3.17 (EP), U4.1 (VEE), U4.4 (VEE), U4.9 (VEE), U4.12 (VEE), U4.17 (EP); also elsewhere on the board
unnamed: C14.2, C15.1, L2.2, R13.2, R14.1
unnamed: C16.1, R15.2
unnamed: C23.2, C24.1, L3.2, R20.2, R21.1
unnamed: C25.1, R22.2
unnamed: C32.2, C33.1, L4.2, R27.2, R28.1
unnamed: C34.1, R29.2
unnamed: D3.2 (A), R16.2
unnamed: D4.2 (A), R23.2
unnamed: D5.2 (A), R30.2
unnamed: C14.1, J2.1 (In), L2.1, R13.1
unnamed: C23.1, J3.1 (In), L3.1, R20.1
unnamed: C32.1, J4.1 (In), L4.1, R27.1
unnamed: C17.1, U2.5 (AEC+)
unnamed: C17.2, U2.6 (AEC-)
unnamed: C16.2, U2.3 (SDI#)
unnamed: C15.2, U2.2 (SDI)
unnamed: C26.1, U3.5 (AEC+)
unnamed: C26.2, U3.6 (AEC-)
unnamed: C25.2, U3.3 (SDI#)
unnamed: C24.2, U3.2 (SDI)
unnamed: C35.1, U4.5 (AEC+)
unnamed: C35.2, U4.6 (AEC-)
unnamed: C34.2, U4.3 (SDI#)
unnamed: C33.2, U4.2 (SDI)

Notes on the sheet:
Decoupling
Input Active
BYPASS needs to be pulled down to enable EQ. MUTE needs to be tied to GND to enable output. MUTE can be tied to CD to mute while no input.

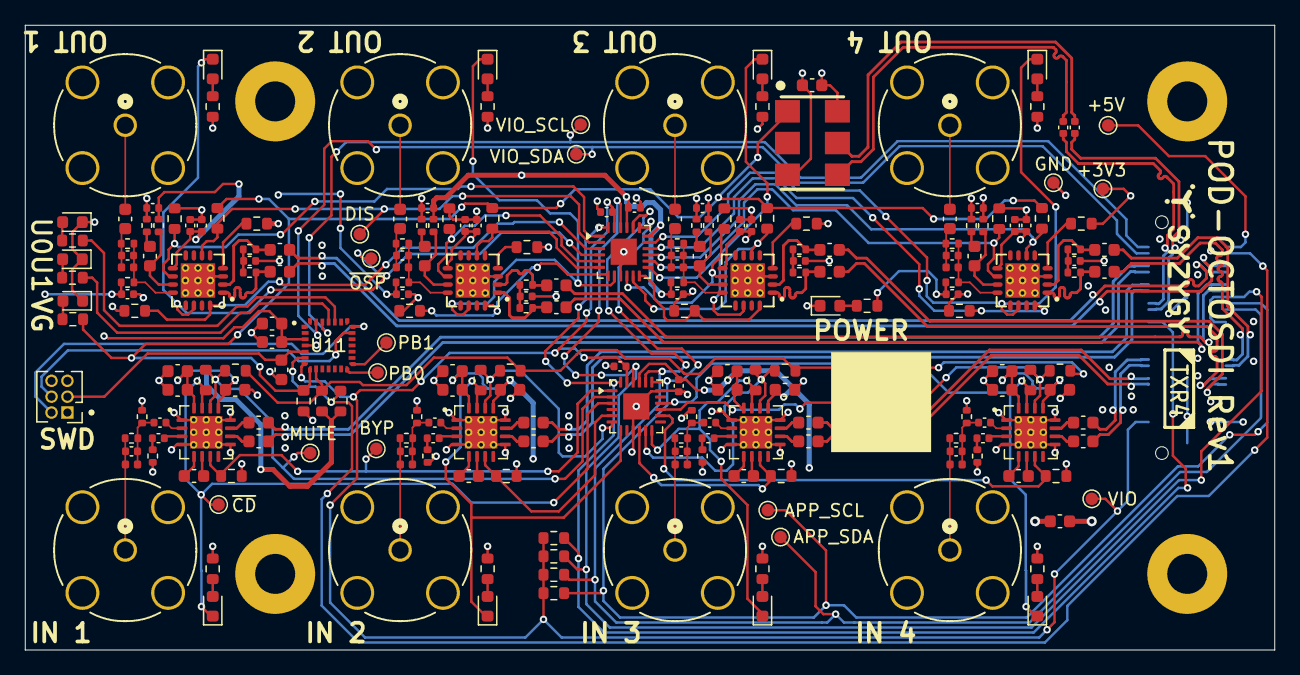
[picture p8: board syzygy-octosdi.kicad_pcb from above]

Board: 4 copper layers, 100.0 x 50.0 mm, 231 parts (1 on the bottom side), 152 nets.

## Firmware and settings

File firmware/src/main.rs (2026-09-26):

#![no_std]
#![no_main]

use defmt_rtt as _;
use panic_probe as _;

#[rtic::app(device = embassy_stm32::pac, peripherals = false, dispatchers = [TIM16, TIM17])]
mod app {
    use embassy_stm32::{
        Peri,
        adc::{Adc, SampleTime, VREF_CALIB_MV},
        gpio::{Level, Output, Speed},
        i2c::{I2c, Master},
        mode::Blocking,
        peripherals::{ADC1, PA1},
    };
    use rtic_monotonics::stm32::prelude::*;

    stm32_tim2_monotonic!(Mono, 1_000_000);

    #[shared]
    struct Shared {}

    #[local]
    struct Local {}

    #[init]
    fn init(_cx: init::Context) -> (Shared, Local) {
        let p = embassy_stm32::init(Default::default());
        Mono::start(embassy_stm32::rcc::clocks(&p.RCC).sys.to_hertz().unwrap().0);

        // Assume VIO is always good; keep both polarity outputs asserted.
        let vio_good = Output::new(p.PA2, Level::Low, Speed::Low);
        let vio_good_n = Output::new(p.PA3, Level::High, Speed::Low);
        let user_0 = Output::new(p.PB4, Level::Low, Speed::Low);
        let user_1 = Output::new(p.PB5, Level::Low, Speed::Low);

        // VIO_I2C is externally bridged to APP_I2C for this bring-up test.
        let mut i2c = I2c::new_blocking(p.I2C1, p.PB6, p.PB7, Default::default());
        if let Some(ports) = read_expander(&mut i2c, 0x20) {
            for channel in 0..4 {
                let group = ports[channel / 2] >> ((channel % 2) * 4);
                defmt::info!(
                    "SDI In {}: BYPASS={} MUTE={} CD_N={}",
                    channel + 1,
                    group & 1 != 0,
                    group & 2 != 0,
                    group & 4 != 0,
                );
            }
        }
        if let Some(ports) = read_expander(&mut i2c, 0x21) {
            for channel in 0..4 {
                let group = ports[channel / 2] >> ((channel % 2) * 4);
                defmt::info!(
                    "SDI Out {}: SD_HD_N={} DISABLE_N={} EQ_EN_N={} OSP_N={}",
                    channel + 1,
                    group & 1 != 0,
                    group & 2 != 0,
                    group & 4 != 0,
                    group & 8 != 0,
                );
            }
        }

        blink::spawn(vio_good, vio_good_n, user_1).ok();
        monitor::spawn(p.ADC1, p.PA1, i2c, user_0).ok();

        (Shared {}, Local {})
    }

    fn read_expander(i2c: &mut I2c<'_, Blocking, Master>, address: u8) -> Option<[u8; 2]> {
        // PCAL6416A configuration bits: 1 = input. Set both eight-bit ports.
        for register in [0x06, 0x07] {
            if let Err(error) = i2c.blocking_write(address, &[register, 0xff]) {
                defmt::error!(
                    "I2C expander 0x{:02x}: input configuration failed: {:?}",
                    address,
                    error
                );
                return None;
            }
        }

        let mut configuration = [0; 2];
        for (index, register) in [0x06, 0x07].into_iter().enumerate() {
            if let Err(error) =
                i2c.blocking_write_read(address, &[register], &mut configuration[index..index + 1])
            {
                defmt::error!(
                    "I2C expander 0x{:02x}: configuration read failed: {:?}",
                    address,
                    error
                );
                return None;
            }
        }
        if configuration != [0xff, 0xff] {
            defmt::error!(
                "I2C expander 0x{:02x}: input configuration mismatch P0={} P1={}",
                address,
                configuration[0],
                configuration[1]
            );
            return None;
        }

        let mut inputs = [0; 2];
        for (index, register) in [0x00, 0x01].into_iter().enumerate() {
            if let Err(error) =
                i2c.blocking_write_read(address, &[register], &mut inputs[index..index + 1])
            {
                defmt::error!(
                    "I2C expander 0x{:02x}: input read failed: {:?}",
                    address,
                    error
                );
                return None;
            }
        }
        defmt::info!(
            "I2C expander 0x{:02x}: all inputs, raw P0={} P1={}",
            address,
            inputs[0],
            inputs[1]
        );
        Some(inputs)
    }

    #[task]
    async fn blink(
        _cx: blink::Context,
        mut vio_good: Output<'static>,
        mut vio_good_n: Output<'static>,
        mut user_1: Output<'static>,
    ) {
        loop {
            // Keep ownership of both outputs for the lifetime of the task.
            vio_good.set_high();
            vio_good_n.set_low();

            user_1.set_high();
            Mono::delay(1000.millis()).await;
            user_1.set_low();
        }
    }

    #[task]
    async fn monitor(
        _cx: monitor::Context,
        adc_peripheral: Peri<'static, ADC1>,
        mut vio: Peri<'static, PA1>,
        mut i2c: I2c<'static, Blocking, Master>,
        mut user_0: Output<'static>,
    ) {
        let mut adc = Adc::new(adc_peripheral);
        let mut vref = adc.enable_vrefint();
        let vref_cal = vref.calibrated_value() as u32;

        loop {
            // U6 port 0 bit 0 is SDI Out 1 SD/~HD; high lights USER_LED_0.
            let mut port_0 = [0u8; 1];
            match i2c.blocking_write_read(0x21, &[0x00], &mut port_0) {
                Ok(()) => {
                    let sd_hd_n = port_0[0] & 1 != 0;
                    if sd_hd_n {
                        user_0.set_high();
                    } else {
                        user_0.set_low();
                    }
                    defmt::info!("SDI Out 1 SD_HD_N={}", sd_hd_n);
                }
                Err(error) => {
                    user_0.set_low();
                    defmt::warn!("SDI Out 1 read failed: {:?}", error);
                }
            }

            let vref_raw = adc.blocking_read(&mut vref, SampleTime::CYCLES160_5) as u32;
            let vio_raw = adc.blocking_read(&mut vio, SampleTime::CYCLES160_5) as u32;
            if vref_raw != 0 {
                let vdda_mv = VREF_CALIB_MV * vref_cal / vref_raw;
                let vio_mv = vio_raw * vdda_mv / 4095;
                defmt::info!("VIO: {} mV", vio_mv);
            } else {
                defmt::warn!("VIO ADC: VREF reading was zero");
            }
            Mono::delay(100.millis()).await;
        }
    }
}

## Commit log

2026-08-15 add most of the schematic
    [quad.kicad_sch, sdi_in.kicad_sch, sdi_out.kicad_sch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]
2026-08-16 implement schematic review feedback
    [quad.kicad_sch, sdi_in.kicad_sch, sdi_out.kicad_sch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]
2026-08-16 substitute bnc connector for better max freq
    [quad.kicad_sch, sdi_in.kicad_sch, sdi_out.kicad_sch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]
2026-08-16 split gpio expanders by inputs/outputs instead of quads
    [inputs.kicad_sch, outputs.kicad_sch, sdi_in.kicad_sch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]
2026-08-17 start laying out channels
    [sdi_in.kicad_sch, sdi_out.kicad_sch, syzygy-octosdi.kicad_pcb]
2026-08-18 finish layout of first in and out channel
    [sdi_in.kicad_sch, sdi_out.kicad_sch, syzygy-octosdi.kicad_pcb]
2026-08-18 route all in/out lanes
    [sdi_in.kicad_sch, syzygy-octosdi.kicad_pcb]
2026-08-19 route the smartvio mcu and the gpio expanders
    [sdi_in.kicad_sch, sdi_out.kicad_sch, smartvio.kicad_sch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]
2026-08-20 route all the low speed io and start 3v3
    [syzygy-octosdi.kicad_pcb, syzygy-octosdi.kicad_sch]
2026-08-21 finish routing
    [sdi_in.kicad_sch, sdi_out.kicad_sch, syzygy-octosdi.kicad_pcb]
2026-08-21 fixes following review and more mounting holes
    [outputs.kicad_sch, sdi_out.kicad_sch, smartvio.kicad_sch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]
2026-08-21 add power led and test points
    [inputs.kicad_sch, outputs.kicad_sch, sdi_in.kicad_sch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]
2026-08-21 add labels and syzygy info
    [syzygy-octosdi.kicad_pcb]
2026-08-22 check against jlcpcb capabilities
    [inputs.kicad_sch, outputs.kicad_sch, sdi_in.kicad_sch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]
2026-08-22 add ibom and pinouts
    [syzygy-octosdi.kicad_pcb]
2026-08-22 add rev info to board files and bom
    [syzygy-octosdi.kicad_pcb]
2026-08-22 add some larger bypass caps to the cable drivers
    [inputs.kicad_sch, outputs.kicad_sch, sdi_in.kicad_sch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]
2026-08-23 specify skus for parts
    [inputs.kicad_sch, outputs.kicad_sch, sdi_in.kicad_sch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]
2026-08-23 specify led colours
    [sdi_in.kicad_sch, sdi_out.kicad_sch, smartvio.kicad_sch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]
2026-08-23 add vio test point
    [inputs.kicad_sch, outputs.kicad_sch, smartvio.kicad_sch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]
2026-08-23 sku and led resistor updates following review
    [sdi_in.kicad_sch, sdi_out.kicad_sch, smartvio.kicad_sch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]
2026-09-25 add firmware to test leds
